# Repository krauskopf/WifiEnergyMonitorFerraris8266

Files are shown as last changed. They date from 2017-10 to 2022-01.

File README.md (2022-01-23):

# WiFi Energy Monitor for electromechanical induction watt-hour meters ('Ferraris-Zähler')

This project contains a firmware and schematic for a WiFi based Energy Monitor which can be connected to a
electromechanical induction watt-hour meters ('Ferraris-Zähler') using the
[ELV Sensor ES-Fer](https://www.elv.de/homematic-zaehlersensor-ferraris-zaehler-es-fer.html), which is normally intended
to be used with the HomeMatic ecosystem. Using the transmission board described here, the sensor data is made available via
WiFi and http RESTfull API. This way it can be used in many other scenarios outside HomeMatic (e.g. Node-Red).

An ESP8266 ESP-12E NodeMcu WiFi board is used for connectivity and sensor evaluation.

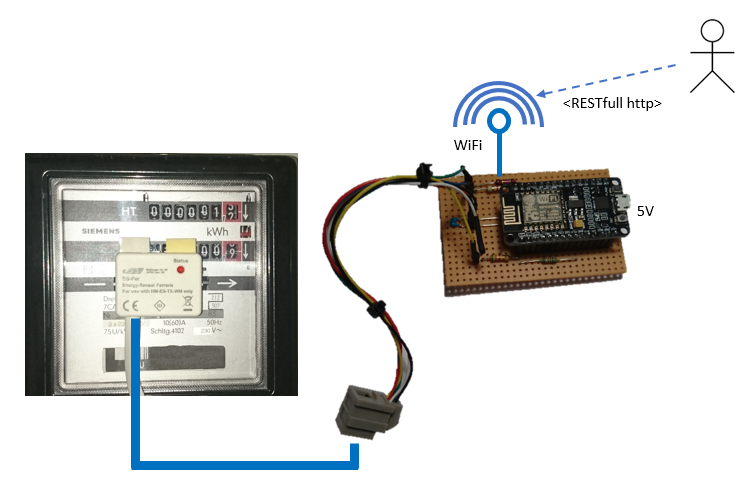
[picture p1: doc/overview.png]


## Usage

### REST-API

The board has a RESTfull http interface which returns all data as json objects.
There is an API description in [OpenAPI 2.0](https://github.com/OAI/OpenAPI-Specification) format in the folder `api`.
It is recommended to use the [Swagger Editor](https://editor.swagger.io/) to open and view the API documentation.
The editor also allows you to generate client code to access the API from the runtime/language of your choice.

Here is also a short summary:

<table><tr><td>Path</td><td>Method</td><td>Summary</td></tr><tr><td>/info</td><td>GET</td><td>Gets info about board and system status.</td></tr><tr><td>/meters</td><td>GET</td><td>Gets the energy meters.</td></tr><tr><td>/meters/{idMeter}</td><td>GET</td><td>Gets an energy meter.</td></tr><tr><td>/meters/{idMeter}/counters</td><td>GET</td><td>Gets the counters of an energy meter.</td></tr><tr><td>/meters/{idMeter}/counters/{idCounter}</td><td>GET</td><td>Gets a single counter of an energy meter.</td></tr><tr><td>/meters/{idMeter}/counters/{idCounter}/kWh</td><td>GET</td><td>Gets the kilowatt-hour of a counter of an energy meter.</td></tr><tr><td>/meters/{idMeter}/counters/{idCounter}/kWh</td><td>PUT</td><td>Set the kilowatt-hour counter of an energy meter.</td></tr><tr><td>/meters/{idMeter}/counters/{idCounter}/revolutions</td><td>GET</td><td>Gets the number of revolutions of the disc of an energy meter.</td></tr><tr><td>/meters/{idMeter}/counters/{idCounter}/revolutions</td><td>PUT</td><td>Set the number of revolutions of the disk of an energy meter.</td></tr><tr><td>/meters/{idMeter}/revsPerKWh</td><td>PUT</td><td>Sets the number of revolutions per kilo watt-hour.</td></tr><tr><td>/meters/{idMeter}/revsPerKWh</td><td>GET</td><td>Gets the number of revolutions per kilo watt-hour.</td></tr><tr><td>/meters/{idMeter}/threshold</td><td>PUT</td><td>Sets the threshold for the sensor of an energy meter.</td></tr><tr><td>/meters/{idMeter}/threshold</td><td>GET</td><td>Gets the threshold for the sensor of an energy meter.</td></tr></table>

## Build instructions

### Hardware

You can find a [fritzing](http://fritzing.org) schematic in the folder `hardware` which shows the pin layout.

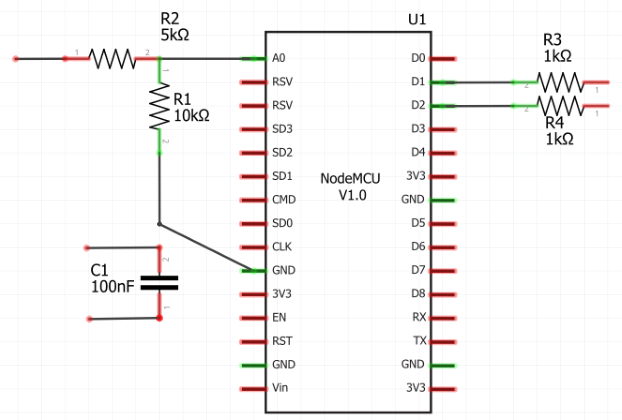
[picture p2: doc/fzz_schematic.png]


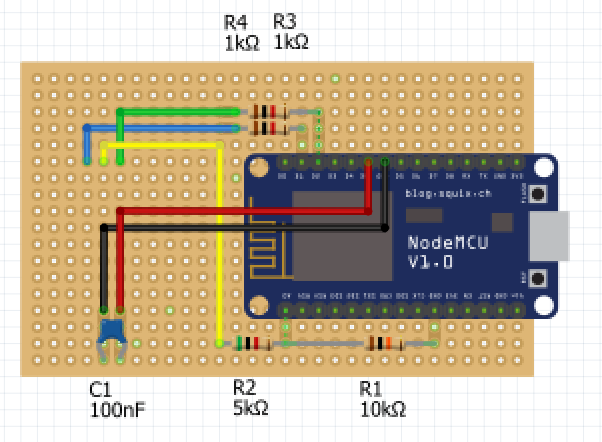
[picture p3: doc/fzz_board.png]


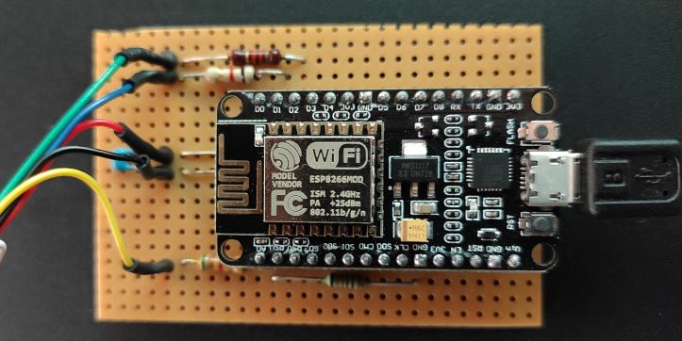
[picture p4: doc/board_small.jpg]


The color layout of the female rj11 connector is shown below:

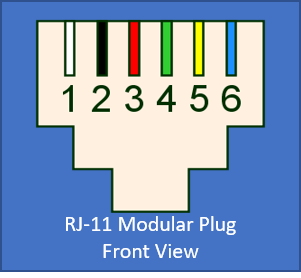
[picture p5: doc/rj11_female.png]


| Pin | Description |
|-----|---|
| 1 | not connected |
| 2 | GND |
| 3 | Power Supply 4,4V (3,3V works too)  |
| 4 | Sensor LED |
| 5 | Sensor Signal |
| 6 | Status LED |

### Firmware

To build the arduino sketch:

- Install Arduino IDE
  - Use the Arduino Board Manager to install the ESP8266 toolchain (https://github.com/esp8266/Arduino)
  - Use the Arduino Library Manager to install ArduinoJSON (https://bblanchon.github.io/ArduinoJson/)
- Open the sketch and modify the settings in the `config.h` header. You have to set the SSID and password of your wifi network.
- Compile and download to nodemcu.

## History

- 2017-oct-01: 0.1.0 - Created first version.
- 2017-oct-12: 1.0.0 - Completed API.

## Credits

- Sebastian Krauskopf (sebakrau)

## License

The MIT License (MIT)

Copyright (c) 2017 sebakrau

Permission is hereby granted, free of charge, to any person obtaining a copy
of this software and associated documentation files (the "Software"), to deal
in the Software without restriction, including without limitation the rights
to use, copy, modify, merge, publish, distribute, sublicense, and/or sell
copies of the Software, and to permit persons to whom the Software is
furnished to do so, subject to the following conditions:

The above copyright notice and this permission notice shall be included in all
copies or substantial portions of the Software.

THE SOFTWARE IS PROVIDED "AS IS", WITHOUT WARRANTY OF ANY KIND, EXPRESS OR
IMPLIED, INCLUDING BUT NOT LIMITED TO THE WARRANTIES OF MERCHANTABILITY,
FITNESS FOR A PARTICULAR PURPOSE AND NONINFRINGEMENT. IN NO EVENT SHALL THE
AUTHORS OR COPYRIGHT HOLDERS BE LIABLE FOR ANY CLAIM, DAMAGES OR OTHER
LIABILITY, WHETHER IN AN ACTION OF CONTRACT, TORT OR OTHERWISE, ARISING FROM,
OUT OF OR IN CONNECTION WITH THE SOFTWARE OR THE USE OR OTHER DEALINGS IN THE
SOFTWARE.

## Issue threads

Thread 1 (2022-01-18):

rj11 female connector pin layout

malvo, 2022-01-18:
i'm unable to find the color layout @ the rj11 female connector. could you provide an overview which pin is connected to which color?

f.e. with pin 1 being on the left side front view and nibble down
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

krauskopf, 2022-01-22:
Sorry for the delay @malvo . Was on a business trip the last days. Added some pics to the readme.md now.

Closed 2022-01-22.

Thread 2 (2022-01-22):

red - GND / black - 3.3V

malvo, 2022-01-22:
i stumbled over the color RED for GND and BLACK for 3.3V from the fritzing is this really correct?
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

krauskopf, 2022-01-23:
Sorry, you are correct. The colors need to be changed. Pin 3 is 3,3V and Pin 2 is GND.

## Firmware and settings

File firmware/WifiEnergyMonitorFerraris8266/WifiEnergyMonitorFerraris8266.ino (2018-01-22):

/*
The MIT License (MIT)

Copyright (c) 2017 sebakrau

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
THE SOFTWARE IS PROVIDED "AS IS", WITHOUT WARRANTY OF ANY KIND, EXPRESS OR
IMPLIED, INCLUDING BUT NOT LIMITED TO THE WARRANTIES OF MERCHANTABILITY,
FITNESS FOR A PARTICULAR PURPOSE AND NONINFRINGEMENT. IN NO EVENT SHALL THE
AUTHORS OR COPYRIGHT HOLDERS BE LIABLE FOR ANY CLAIM, DAMAGES OR OTHER
LIABILITY, WHETHER IN AN ACTION OF CONTRACT, TORT OR OTHERWISE, ARISING FROM,
OUT OF OR IN CONNECTION WITH THE SOFTWARE OR THE USE OR OTHER DEALINGS IN THE
SOFTWARE.
*/
#include <ESP8266WiFi.h>
#include <ESP8266WebServer.h>
#include <ESP8266mDNS.h>
#include <WiFiUdp.h>          // OTA
#include <ArduinoOTA.h>       // OTA
#include <ArduinoJson.h>
extern "C" {
  // include timer library for esp8266
  #include "user_interface.h"
}
#include "WifiClientPrint.h"
#include "config.h"


//
// Types
//
typedef struct Sensor {
  unsigned int value;
  unsigned int threshold;
  unsigned int counter[2];
  unsigned int revsPerKWh;
  bool state;
  bool stateOld;
} Sensor;

//
// Globals
//
ESP8266WebServer g_server(80);
os_timer_t g_timer;
Sensor g_sensors[CONFIG_NUM_SENSORS];






//
// LED
//
void LED_init() {
  pinMode(PIN_BOARD_LED, OUTPUT); 
}

void LED_board_set(bool enabled) {
  if (enabled) {
    digitalWrite(PIN_BOARD_LED, HIGH); 
  } else {
    digitalWrite(PIN_BOARD_LED, LOW); 
  }
}


//
// Timer
//
void SENSOR_setStatusLed(int index, bool enabled) {
  int pin;
  switch(index) {
    case 0: pin = PIN_STATUS_LED_1; break;
    case 1: pin = PIN_STATUS_LED_2; break;
    default: return;
  }
  
  if (enabled) {
    digitalWrite(pin, LOW);
  } else {
    digitalWrite(pin, HIGH); 
  }
}

void SENSOR_setSensorLed(int index, bool enabled) {
  int pin;
  switch(index) {
    case 0: pin = PIN_SENSOR_LED_1; break;
    case 1: pin = PIN_SENSOR_LED_2; break;
    default: return;
  }
  
  if (enabled) {
    digitalWrite(pin, HIGH); 
  } else {
    digitalWrite(pin, LOW); 
  }
}

void SENSOR_sample(void *pArg) {
  const int index = 0;

  // read sensor value through adc. Active LED only for a short time to save energy.
  SENSOR_setSensorLed(index, true);
  g_sensors[index].value = analogRead(PIN_SENSOR);
  SENSOR_setSensorLed(index, false);

  // debounce the sensor value to prevent that a flickering or jittering 
  // sensorValue will falsly increase the counter.
  static int counter = 0;
  if (g_sensors[index].value > g_sensors[index].threshold) {
    
    if (counter > 3) {
      g_sensors[index].state = true;
    } else {
      counter++;
    }
    
  } else if (g_sensors[index].value <= g_sensors[index].threshold) {
    
    if (counter < -3) {
      g_sensors[index].state = false;
    } else {
      counter--;
    }
  } 
  
  // check if there was a rising or falling edge of the signal
  if (g_sensors[index].state != g_sensors[index].stateOld) {
    if (g_sensors[index].state) {
      g_sensors[index].counter[0]++;
      g_sensors[index].counter[1]++;
    }
    SENSOR_setStatusLed(0, g_sensors[index].state);
  }

  g_sensors[index].stateOld = g_sensors[index].state;
} 

void SENSOR_switchMultiplexer(int index) {
  // TODO. Use multiplexer to support multiple connected sensors.
}

void SENSOR_init() {
  pinMode(PIN_STATUS_LED_1, OUTPUT); 
  pinMode(PIN_SENSOR_LED_1, OUTPUT); 
  pinMode(PIN_STATUS_LED_2, OUTPUT); 
  pinMode(PIN_SENSOR_LED_2, OUTPUT); 
  SENSOR_setStatusLed(0, false);
  SENSOR_setStatusLed(1, false);
  SENSOR_setSensorLed(0, false);
  SENSOR_setSensorLed(1, false);
  SENSOR_switchMultiplexer(0);

  for (int i = 0; i < CONFIG_NUM_SENSORS; i++) {
    g_sensors[i].value = 0;
    g_sensors[i].threshold = 150;
    g_sensors[i].revsPerKWh = 75;
    g_sensors[i].counter[0] = 0;
    g_sensors[i].counter[1] = 0;
    g_sensors[i].state = false;
    g_sensors[i].stateOld = false;
  }
   
  os_timer_setfn(&g_timer, SENSOR_sample, NULL);
  os_timer_arm(&g_timer, 20, true);
}


//
// WiFi
//
void WIFI_enableOTA() {
  // Port defaults to 8266
  // ArduinoOTA.setPort(8266);

  // Hostname defaults to esp8266-[ChipID]
  // ArduinoOTA.setHostname("myesp8266");

  // No authentication by default
  // ArduinoOTA.setPassword((const char *)"123");

  ArduinoOTA.onStart([]() {
    Serial.println("OTA: Start");
  });
  ArduinoOTA.onEnd([]() {
    Serial.println("\nEnd");
  });
  ArduinoOTA.onProgress([](unsigned int progress, unsigned int total) {
    Serial.printf("Progress: %u%%\r", (progress / (total / 100)));
  });
  ArduinoOTA.onError([](ota_error_t error) {
    Serial.printf("OTA Error[%u]: ", error);
    if (error == OTA_AUTH_ERROR) Serial.println("Auth Failed");
    else if (error == OTA_BEGIN_ERROR) Serial.println("Begin Failed");
    else if (error == OTA_CONNECT_ERROR) Serial.println("Connect Failed");
    else if (error == OTA_RECEIVE_ERROR) Serial.println("Receive Failed");
    else if (error == OTA_END_ERROR) Serial.println("End Failed");
  });
  ArduinoOTA.begin();
}

void WIFI_init() {
  Serial.print("Connecting to ");
  Serial.println(CONFIG_WIFI_SSID);

  WiFi.begin(CONFIG_WIFI_SSID, CONFIG_WIFI_PASSWORD);

  while (WiFi.status() != WL_CONNECTED) {
    delay(500);
    Serial.print(".");
  }
  Serial.println("");
  Serial.print("WiFi connected, IP: ");
  Serial.println(WiFi.localIP());

#ifdef CONFIG_ENABLE_OTA
  Serial.println("OTA update is enabled!");
  WIFI_enableOTA();
#else  
  Serial.println("OTA update is disabled!");
#endif
}


//
// WEB
//
void WEB_handleNotFound() {
#ifdef CONFIG_DEBUG_NOTFOUND
  String message = "File Not Found\n\n";
  message += "URI: ";
  message += g_server.uri();
  message += "\nMethod: ";
  message += (g_server.method() == HTTP_GET) ? "GET" : "POST";
  message += "\nArguments: ";
  message += g_server.args();
  message += "\n";

  for (int i = 0; i < g_server.args(); i++) {
    message += " " + g_server.argName(i) + ": " + g_server.arg(i) + "\n";
  }

  g_server.send(404, "text/plain", message);
#else
  g_server.send(404, "text/plain", "Not Found!");
#endif
}

void WEB_handleRoot() {
  char temp[1024];
  int sec = millis() / 1000;
  int min = sec / 60;
  int hr = min / 60;

  int cx = snprintf(temp, sizeof(temp),
    "<html>\
      <head>\
        <meta http-equiv='refresh' content='5'/>\
        <title>WifiEnergyMonitor for Ferraris</title>\
        <style>\
          body { background-color: #cccccc; font-family: Arial, Helvetica, Sans-Serif; Color: #000088; }\
        </style>\
      </head>\
      <body>\
        <h1>WifiEnergyMonitor for Ferraris-Counter (ESP8266)!</h1>\
        <p>Version: %d.%d.%d</p>\
        <p>Uptime: %02d:%02d:%02d</p>\
        <div style=\"white-space: pre-wrap;\">"
    ,
    APP_VERSION_MAJOR, APP_VERSION_MINOR, APP_VERSION_PATCH,
    hr, min % 60, sec % 60
  );

  if (cx < 0) {
    g_server.send(200, "text/html", "Error: buffer too small.");  
  } else {

    // append meter info
    StaticJsonBuffer<400> jsonBuffer;
    JsonObject& root = jsonBuffer.createObject();
    WEB_buildMeter(0, root);
    cx += root.prettyPrintTo(&temp[cx], sizeof(temp) - strlen("</div></body></html> ") - cx);
  
    // append closing tags
    strcat(&temp[cx], "</div></body></html>");
  }
  
  g_server.send(200, "text/html", temp);
}

template<class T> void WEB_sendJson(const T& json) {
  g_server.setContentLength(json.measureLength());
  g_server.send(200, "application/json", "");
  WiFiClientPrint<> p(g_server.client());
  json.printTo(p);
  p.stop(); // Calls p.flush() and WifiClient.stop()
}

void WEB_handleApiInfo() {
  String version = "";
  version += APP_VERSION_MAJOR;
  version += ".";
  version += APP_VERSION_MINOR;
  version += ".";
  version += APP_VERSION_PATCH;

  int sec = millis() / 1000;
  int min = sec / 60;
  int hr = min / 60;
  String uptime = "";
  uptime += hr;
  uptime += ":";
  uptime += min % 60;
  uptime += ":";
  uptime += sec % 60;

  StaticJsonBuffer<300> jsonBuffer;
  JsonObject& root = jsonBuffer.createObject();
  root["name"] = APP_NAME;
  root["version"] = version;
  root["uptime"] = uptime;
  WEB_sendJson(root);
}

void WEB_handleApiThreshold(int indexMeter) {
  switch (g_server.method()) {
    case HTTP_GET:
      {
        String content = "";
        content += g_sensors[indexMeter].threshold;
        g_server.send(200, "text/plain", content);
      }
      break;
    case HTTP_PUT:
      {
        String value = g_server.arg("value");
        if (value) {
          g_sensors[indexMeter].threshold = value.toInt();
          g_server.send(200, "text/plain", "OK!");
        } else {
          g_server.send(400, "text/plain", "Missing argument 'value'!");
        }      
      }
      break;
    default:
      {
        g_server.send(405, "text/plain", "The resource doesn't support the specified HTTP verb.!");
      }
      break;
  }
}

void WEB_handleApiRevsPerKWh(int indexMeter) {
  switch (g_server.method()) {
    case HTTP_GET:
      {
        String content = "";
        content += g_sensors[indexMeter].revsPerKWh;
        g_server.send(200, "text/plain", content);
      }
      break;
    case HTTP_PUT:
      {
        String value = g_server.arg("value");
        if (value) {
          g_sensors[indexMeter].revsPerKWh = value.toInt();
          g_server.send(200, "text/plain", "OK!");
        } else {
          g_server.send(400, "text/plain", "Missing argument 'value'!");
        }      
      }
      break;
    default:
      {
        g_server.send(405, "text/plain", "The resource doesn't support the specified HTTP verb.!");
      }
      break;
  }
}

void WEB_handleApiCounterRevolutions(int indexMeter, int indexCounter) {
  switch (g_server.method()) {
    case HTTP_GET:
      {
        String content = "";
        content += g_sensors[indexMeter].counter[indexCounter];
        g_server.send(200, "text/plain", content);
      }
      break;
    case HTTP_PUT:
      {
        String value = g_server.arg("value");
        if (value) {
          g_sensors[indexMeter].counter[indexCounter] = value.toInt();
          g_server.send(200, "text/plain", "OK!");
        } else {
          g_server.send(400, "text/plain", "Missing argument 'value'!");
        }      
      }
      break;
    default:
      {
        g_server.send(405, "text/plain", "The resource doesn't support the specified HTTP verb.!");
      }
      break;
  }
}

void WEB_handleApiCounterKWh(int indexMeter, int indexCounter) {
  switch (g_server.method()) {
    case HTTP_GET:
      {
        String content = "";
        content += static_cast<double>(g_sensors[indexMeter].counter[indexCounter]) / g_sensors[indexMeter].revsPerKWh;
        g_server.send(200, "text/plain", content);
      }
      break;
    case HTTP_PUT:
      {
        String value = g_server.arg("value");
        if (value) {
          g_sensors[indexMeter].counter[indexCounter] = strtod(value.c_str(), 0) * g_sensors[indexMeter].revsPerKWh;
          g_server.send(200, "text/plain", "OK!");
        } else {
          g_server.send(400, "text/plain", "Missing argument 'value'!");
        }      
      }
      break;
    default:
      {
        g_server.send(405, "text/plain", "The resource doesn't support the specified HTTP verb.!");
      }
      break;
  }
}



void WEB_buildCounter(int indexMeter, int indexCounter, JsonObject& jsonObject) {
  jsonObject["id"] = indexCounter + 1;
  jsonObject["revolutions"] = g_sensors[indexMeter].counter[indexCounter];
  jsonObject["kWh"] = static_cast<double>(g_sensors[indexMeter].counter[indexCounter]) / g_sensors[indexMeter].revsPerKWh;  
}

void WEB_handleApiCounter(int indexMeter, int indexCounter) {
  StaticJsonBuffer<200> jsonBuffer;
  JsonObject& root = jsonBuffer.createObject();
  WEB_buildCounter(indexMeter, indexCounter, root);
  WEB_sendJson(root);
}

void WEB_handleApiCounters(int indexMeter) {
  StaticJsonBuffer<200> jsonBuffer;
  JsonArray& root = jsonBuffer.createArray();
  JsonObject& counter1 = root.createNestedObject();
  WEB_buildCounter(indexMeter, 0, counter1);
  JsonObject& counter2 = root.createNestedObject();
  WEB_buildCounter(indexMeter, 1, counter2);
  WEB_sendJson(root);
}

void WEB_buildMeter(int indexMeter, JsonObject& jsonObject) {
  jsonObject["id"] = indexMeter + 1;
  jsonObject["value"] = g_sensors[indexMeter].value;
  jsonObject["state"] = g_sensors[indexMeter].state;
  jsonObject["threshold"] = g_sensors[indexMeter].threshold;
  jsonObject["revsPerKWh"] = g_sensors[indexMeter].revsPerKWh;

  JsonArray& counters = jsonObject.createNestedArray("counters");
  JsonObject& counter1 = counters.createNestedObject();
  WEB_buildCounter(indexMeter, 0, counter1);
  JsonObject& counter2 = counters.createNestedObject();
  WEB_buildCounter(indexMeter, 1, counter2);
}

void WEB_handleApiMeter(int indexMeter) {
  StaticJsonBuffer<400> jsonBuffer;
  JsonObject& root = jsonBuffer.createObject();
  WEB_buildMeter(indexMeter, root);
  WEB_sendJson(root);
}

void WEB_handleApiMeters() {
  StaticJsonBuffer<600> jsonBuffer;
  JsonArray& root = jsonBuffer.createArray();
  JsonObject& meter1 = root.createNestedObject();
  WEB_buildMeter(0, meter1);
  JsonObject& meter2 = root.createNestedObject();
  WEB_buildMeter(1, meter2);
  WEB_sendJson(root);
}

void WEB_init() {
  g_server.onNotFound(WEB_handleNotFound);
  g_server.on("/", HTTP_GET, WEB_handleRoot);

  //
  // API interface
  //
  g_server.on("/api/ping", []() {
    g_server.send(200, "text/plain", "pong");
  });
  
  g_server.on("/api/info", HTTP_GET, WEB_handleApiInfo);
  g_server.on("/api/meters", HTTP_GET, WEB_handleApiMeters);
  g_server.on("/api/meters/1", HTTP_GET, [](){ WEB_handleApiMeter(0); });
  g_server.on("/api/meters/1/threshold", HTTP_ANY, [](){ WEB_handleApiThreshold(0); });
  g_server.on("/api/meters/1/revsPerKWh", HTTP_ANY, [](){ WEB_handleApiRevsPerKWh(0); });
  g_server.on("/api/meters/1/counters", HTTP_GET, [](){ WEB_handleApiCounters(0); });
  g_server.on("/api/meters/1/counters/1", HTTP_GET, [](){ WEB_handleApiCounter(0, 0); });
  g_server.on("/api/meters/1/counters/1/revolutions", HTTP_ANY, [](){ WEB_handleApiCounterRevolutions(0, 0); });
  g_server.on("/api/meters/1/counters/1/kWh", HTTP_ANY, [](){ WEB_handleApiCounterKWh(0, 0); });
  g_server.on("/api/meters/1/counters/2", HTTP_GET, [](){ WEB_handleApiCounter(0, 1); });
  g_server.on("/api/meters/1/counters/2/revolutions", HTTP_ANY, [](){ WEB_handleApiCounterRevolutions(0, 1); });
  g_server.on("/api/meters/1/counters/1/kWh", HTTP_ANY, [](){ WEB_handleApiCounterKWh(0, 1); });
  g_server.on("/api/meters/2", HTTP_GET, [](){ WEB_handleApiMeter(1); });
  g_server.on("/api/meters/2/threshold", HTTP_ANY, [](){ WEB_handleApiThreshold(1); });
  g_server.on("/api/meters/2/revsPerKWh", HTTP_ANY, [](){ WEB_handleApiRevsPerKWh(1); });
  g_server.on("/api/meters/2/counters", HTTP_GET, [](){ WEB_handleApiCounters(1); });
  g_server.on("/api/meters/2/counters/1", HTTP_GET, [](){ WEB_handleApiCounter(1, 0); });
  g_server.on("/api/meters/1/counters/1/revolutions", HTTP_ANY, [](){ WEB_handleApiCounterRevolutions(1, 0); });
  g_server.on("/api/meters/1/counters/1/kWh", HTTP_ANY, [](){ WEB_handleApiCounterKWh(1, 0); });
  g_server.on("/api/meters/2/counters/2", HTTP_GET, [](){ WEB_handleApiCounter(1, 1); });
  g_server.on("/api/meters/1/counters/1/revolutions", HTTP_ANY, [](){ WEB_handleApiCounterRevolutions(1, 1); });
  g_server.on("/api/meters/1/counters/1/kWh", HTTP_ANY, [](){ WEB_handleApiCounterKWh(1, 1); });
  g_server.begin();
  Serial.println("HTTP g_server started");
}


//
// Setup
//
void setup() {
  // Init board
  LED_init();
  LED_board_set(true);
  Serial.begin(115200);
  delay(10);
  Serial.println();
  Serial.println();

  // Init sensor
  SENSOR_init();

  // Connect WiFi 
  WIFI_init();

  // Start server interface
  WEB_init();

  // Go, go, go...
  Serial.println("READY");
  LED_board_set(false);
}


//
// LOOP
//
void loop() {
  g_server.handleClient();
#ifdef CONFIG_ENABLE_OTA
  ArduinoOTA.handle();
#endif
}

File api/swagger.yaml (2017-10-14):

swagger: '2.0'
info:
  description: >-
    This is an energy monitor for electromechanical induction watt-hour meters
    ('Ferraris-Zähler')
  version: 1.0.0
  title: WifiEnergyMonitorFerraris
  contact:
    name: Sebastian Krauskopf
    email: mail@sebakrau.de
  license:
    name: MIT
    url: 'https://opensource.org/licenses/MIT'
basePath: /api
schemes:
  - http
paths:
  /meters:
    get:
      summary: Gets the energy meters.
      description: Returns the list of energy meters.
      tags:
        - EnergyMeters
      responses:
        '200':
          description: A list of energy meters.
          schema:
            $ref: '#/definitions/Meters'
  '/meters/{idMeter}':
    get:
      summary: Gets an energy meter.
      description: Returns a single energy meter and its configuration.
      tags:
        - EnergyMeters
      parameters:
        - $ref: '#/parameters/idMeter'
      responses:
        '200':
          description: A meter
          schema:
            $ref: '#/definitions/Meter'
        '404':
          description: The meter does not exist.
  '/meters/{idMeter}/threshold':
    get:
      summary: Gets the threshold for the sensor of an energy meter.
      description: >-
        If the value detected by the sensor is above this threshold, than the
        value is interpreted as digit and increments the counter.
      tags:
        - EnergyMeters
      parameters:
        - $ref: '#/parameters/idMeter'
      responses:
        '200':
          description: The threshold value.
          schema:
            type: string
        '404':
          description: The meter does not exist.
    put:
      summary: Sets the threshold for the sensor of an energy meter.
      description: >-
        If the value detected by the sensor is above this threshold, than the
        value is interpreted as digit and increments the counter.
      tags:
        - EnergyMeters
      parameters:
        - $ref: '#/parameters/idMeter'
      responses:
        '200':
          description: OK
        '404':
          description: The meter does not exist.
  '/meters/{idMeter}/revsPerKWh':
    get:
      summary: Gets the number of revolutions per kilo watt-hour.
      description: >-
        Get the configuration value which describes the number of revolutions
        necessary to consume 1 kilo watt-hour.
      tags:
        - EnergyMeters
      parameters:
        - $ref: '#/parameters/idMeter'
      responses:
        '200':
          description: The revsPerKWh value.
          schema:
            type: string
        '404':
          description: The meter does not exist.
    put:
      summary: Sets the number of revolutions per kilo watt-hour.
      description: >-
        Set the configuration value which describes the number of revolutions
        necessary to consume 1 kilo watt-hour.
      tags:
        - EnergyMeters
      parameters:
        - $ref: '#/parameters/idMeter'
      responses:
        '200':
          description: OK
        '404':
          description: The meter does not exist.
  '/meters/{idMeter}/counters':
    get:
      summary: Gets the counters of an energy meter.
      description: Returns the list of counters for an energy meter.
      tags:
        - EnergyMeters
      parameters:
        - $ref: '#/parameters/idMeter'
      responses:
        '200':
          description: A list of counters for an energy meter.
          schema:
            $ref: '#/definitions/Counters'
  '/meters/{idMeter}/counters/{idCounter}':
    get:
      summary: Gets a single counter of an energy meter.
      description: Returns a counter with all its values for an energy meter.
      tags:
        - EnergyMeters
      parameters:
        - $ref: '#/parameters/idMeter'
        - $ref: '#/parameters/idCounter'
      responses:
        '200':
          description: A list of counters for an energy meter.
          schema:
            $ref: '#/definitions/Counters'
        '404':
          description: The meter or counter does not exist.
  '/meters/{idMeter}/counters/{idCounter}/revolutions':
    get:
      summary: Gets the number of revolutions of the disc of an energy meter.
      description: >-
        Gets the revolutions counter will be incremented on every digit that is
        detected by the sensor.
      tags:
        - EnergyMeters
      parameters:
        - $ref: '#/parameters/idMeter'
        - $ref: '#/parameters/idCounter'
      responses:
        '200':
          description: The value of the counter.
          schema:
            type: string
        '404':
          description: The meter or counter does not exist.
    put:
      summary: Set the number of revolutions of the disk of an energy meter.
      description: >-
        Allows to set the revolutions counter, which will be incremented on
        every digit that is detected by the sensor.
      tags:
        - EnergyMeters
      parameters:
        - $ref: '#/parameters/idMeter'
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

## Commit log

2017-10-11 Initial commit with first working prototype.
    [WifiEnergyMonitorFerraris8266.fzz]
2017-10-11 Added support for ArduinoOTA
2017-10-14 Added missing resource 'revsPerKWh' in api description
    [WifiEnergyMonitorFerraris8266.ino, swagger.yaml]
2018-01-22 Activate sensor LED only when sampling and show status in web root.
2022-01-22 docs: add images of board and pin assignment to fix #1
2022-01-23 docs: fix colors is board schematic (GND <-> U) #2
    [WifiEnergyMonitorFerraris8266.fzz]
